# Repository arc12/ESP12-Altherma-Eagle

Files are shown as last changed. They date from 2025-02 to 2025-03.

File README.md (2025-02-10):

# ESP12 PCB for ESPAltherma

## Power
The normal use case, i.e. operating in the HP, is for the HP to power the board. JP1 is effectively an emergency disconnect feature and is normally on.

## Flashing
The firmware supports "Over The Air" updating but initial flashing will be via the Serial header. This initial flashing should be done without X10A being connected to the heat pump.

If testing with a 5V USB/Serial adapter attached to X10A then JP2 should be removed.

## Runtime Switches
__S1__ (Reset) - ESP-12 reset.
__S2__ is optional, see notes on Serial, below

## Headers
### Serial
UART pins and power, intended for initial flashing the device and diagnostic monitoring using a BT module. When using a Bluetooth serial monitor, JP2 should be on, to supply it with power. Note that the pin labels are to match those on the serial device, rather than being those of the ESP8622.  3.3V logic must be used.

Note that, if the DTR and RTS signals are connected (and D2 installed), then the PlatformIO monitor (or any other serial interaction which is not bootloading) must be configured as follows (add to platformio.ini), otherwise attempts to use the Monitor cause the board to hang (recovers if the monitor is killed):
```
monitor_rts = 0
monitor_dtr = 0
```

If DTR is not available on the USB/Serial adapter, install S2 and R16 and cut through SJ1 and SJ2 for manual boot-loader trigger.
__S2__ (Flash) -  Reset will trigger the boot loader if this switch is held on (i.e. flashing is done by holding S2 and then pressing/releasing S1). Once the new programme has been flashed, S1 (reset) must be done manually.

## Off-board "Thermo" Relay
See the ESPAltherma documentation for notes on the use of a relay to simulate a thermostat in order to on/off control the HP. This is a mains voltage relay AFAIK and in the interest of safety I decided to keep mains off the PCB. Hence there is a header to connect the GPIO to an off-board relay (which should ideally have an opto-coupler and suitable isolation gaps). A solder-jumper (SJ3) is used to allow selection of 3.3V or 5V for the header.

## Options
### LED Signalling
The battery of LEDs and associated Rs, plus JP3 allow for the output states to be signalled. JP3 allows for this signalling to be disconnected/reconnected as required. The external "thermo" relay is assumed to have its own signal.

If the LEDs are not fitted then the pad nearest to "L1", "SG1", etc may be used as a test point.

The ESP-12 modules have a LED on GPIO2, which is used as a "booted and running OK" signal.

### Bluetooth Monitoring
May be achieved by connecting a BT Serial module to the Serial header. Connect JP2 to power the module. NB this is 3.3V.

### Smart Grid OR Power Limitation
These two features use the same GPIO; only fit one set of components!

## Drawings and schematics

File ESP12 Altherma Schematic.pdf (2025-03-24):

## Device substitution:

TLP291-4 JST⁻EH JST⁻PA PCB TX/TX marking is correct for ESP⁸²⁶⁶ but RTS/DTR is correct for USB/Serial adapter.

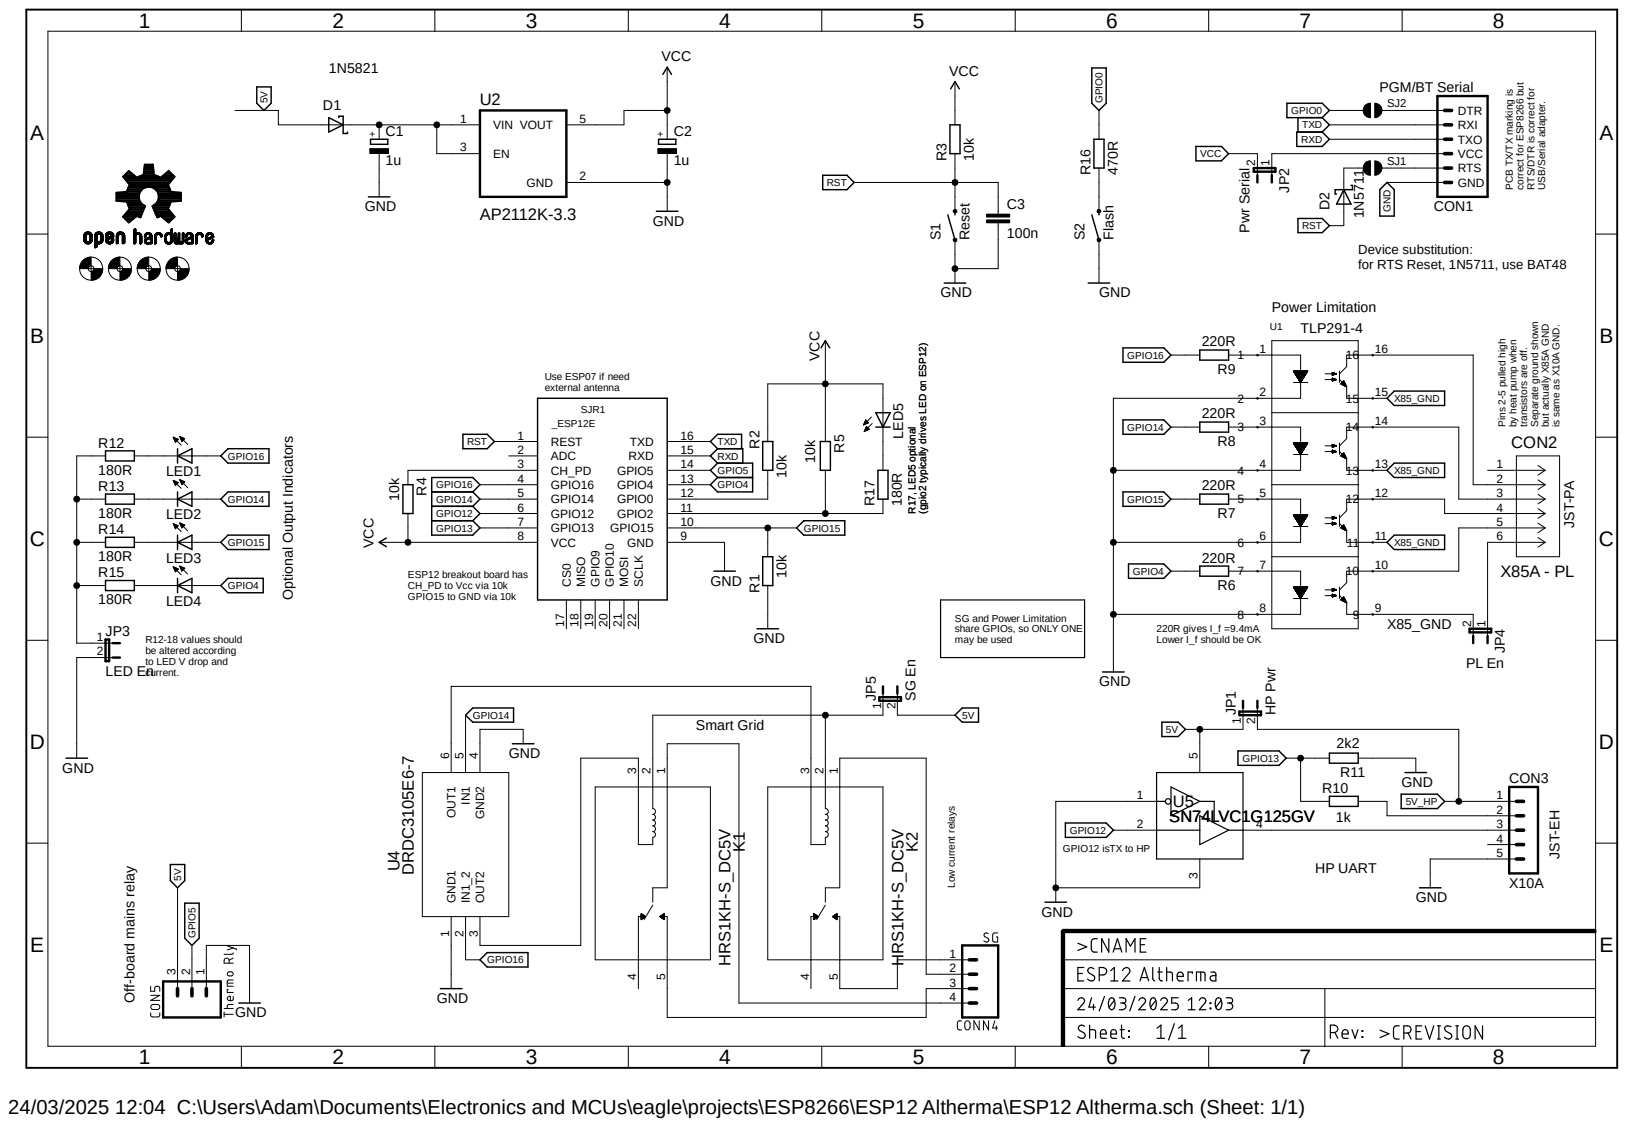
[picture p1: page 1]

for RTS Reset, 1N5711, use BAT48

external antenna Optional Output Indicators

SG and Power Limitation
share GPIOs, so ONLY ONE
may be used

R12-18 values should
be altered according
to LED V drop and
LED En

GPIO12 isTX to HP Low current relays

HP UART Off-board mains relay

24/03/2025 12:04 C:\Users\Adam\Documents\Electronics and MCUs\eagle\projects\ESP8266\ESP12 Altherma\ESP12 Altherma.sch (Sheet: 1/1)

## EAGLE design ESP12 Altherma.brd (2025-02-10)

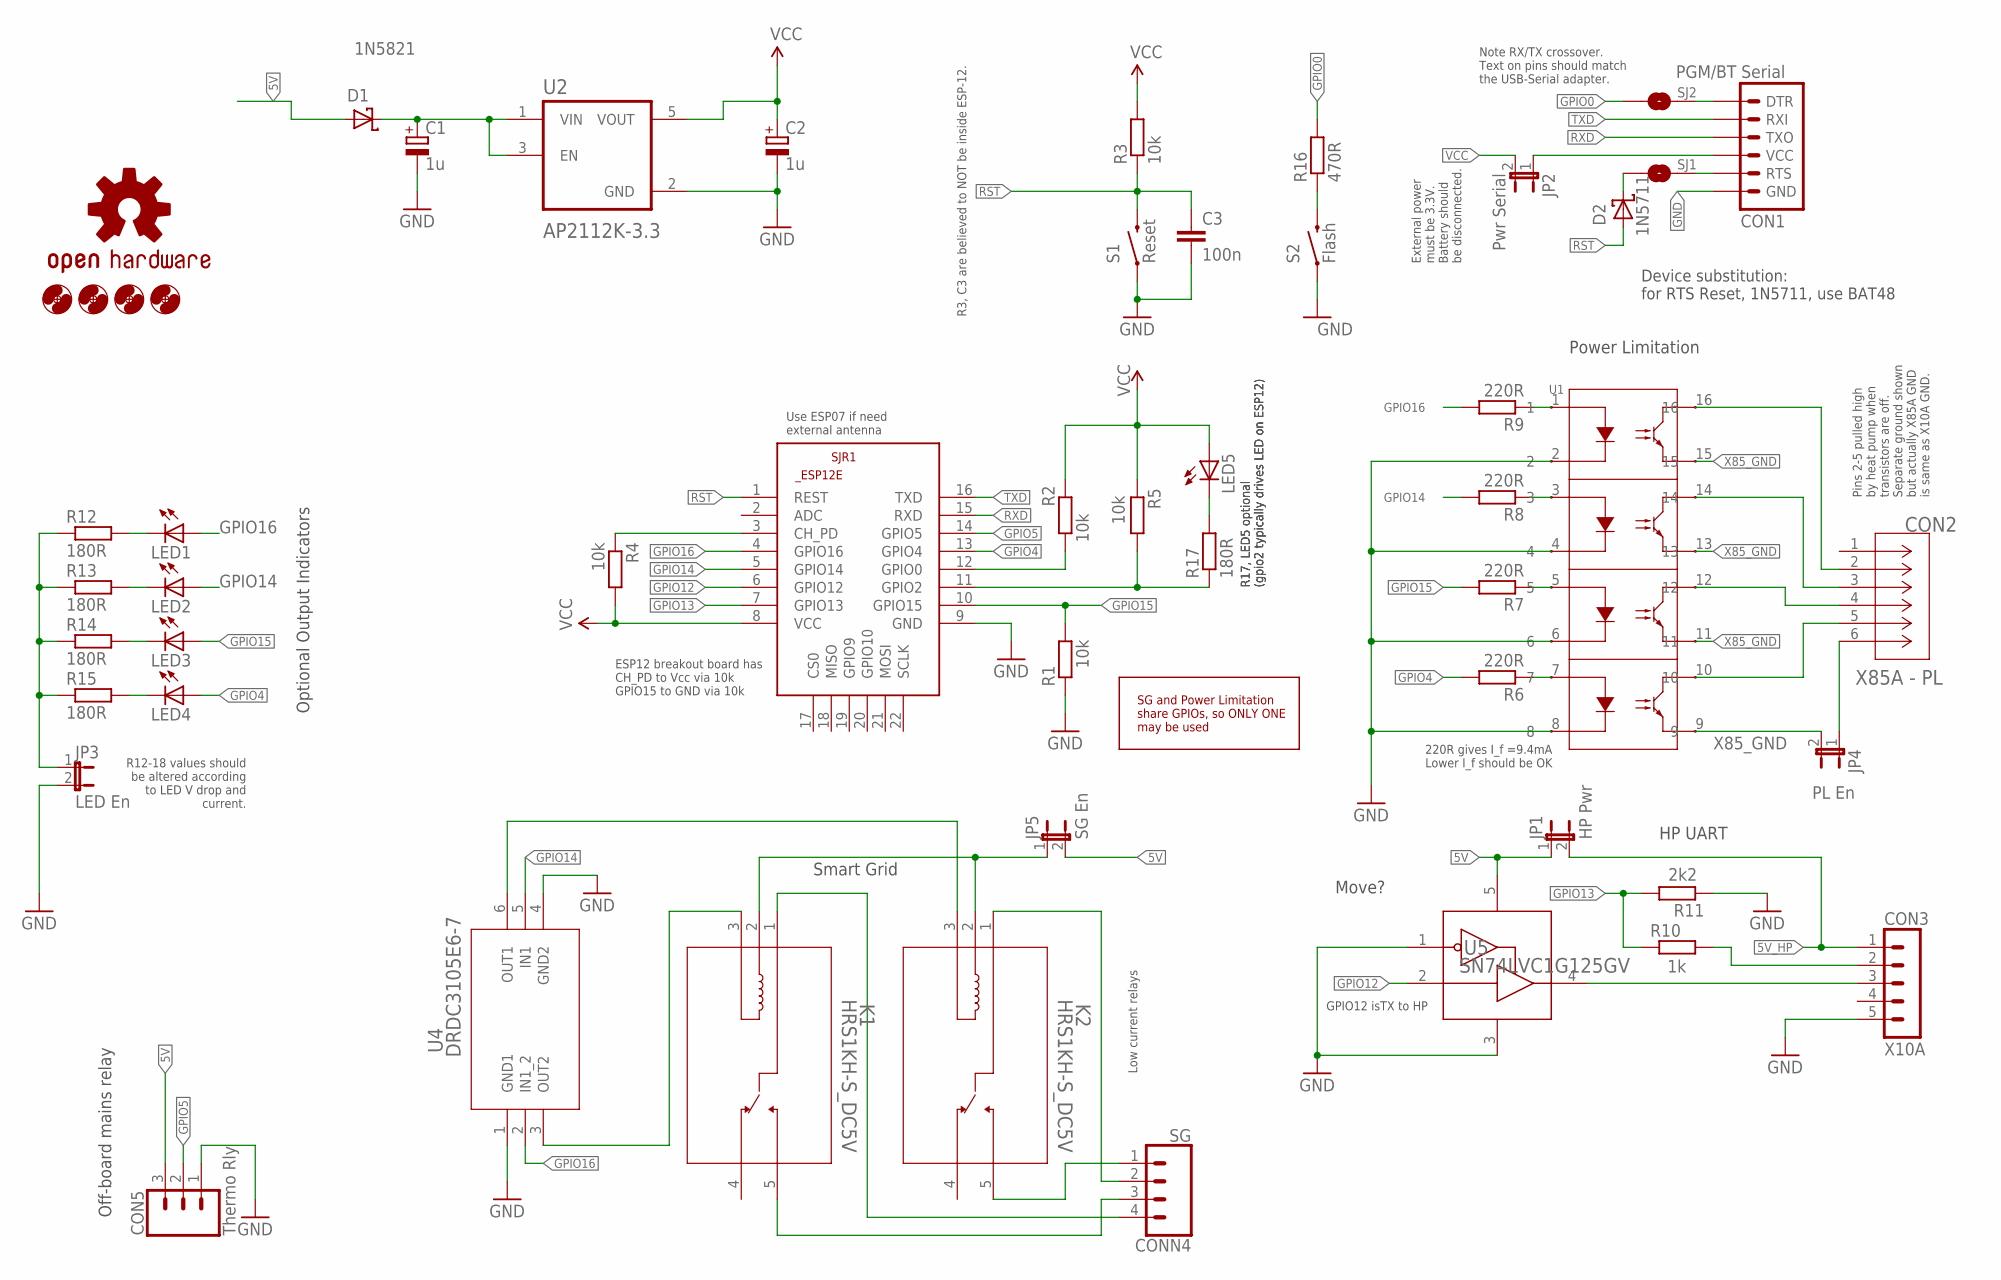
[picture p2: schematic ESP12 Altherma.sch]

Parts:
C1, C2: 1u; E2,5-5
C3: 100n; 1206
CON1: PGM/BT Serial; 1X06-KIT
CON2: X85A - PL; CONN_B06B-PASK_JST
CON3: X10A; B5B-EH-A
CON5: Thermo Rly; 1X03
CONN4: SG; 1X04
D1: 1N5821; DO201-15
D2: 1N5711; DO35-7
H1, H2, H3, H4: MOUNT-HOLE3.2; 3,2
JP1: HP Pwr; 1X02
JP2: Pwr Serial; 1X02
JP3: LED En; 1X02
JP4: PL En; 1X02
JP5: SG En; 1X02
K1, K2: HRS1KH-S_DC5V; HRS1KH-S_DC5V_MTC
LED1, LED2, LED3, LED4, LED5: LED1206; LED-1206
LOGO1: OSHW-LOGOM; OSHW-LOGO-M
R1, R2, R3, R4, R5: 10k; 1206
R6, R7, R8, R9: 220R; 1206
R10: 1k; 1206
R11: 2k2; 1206
R12, R13, R14, R15, R17: 180R; 1206
R16: 470R; 0204/7
S1: Reset; TACTILE-PTH
S2: Flash; TACTILE-PTH
SJ1, SJ2: SOLDERJUMPERTRACE; SJ_2S-TRACE
SJR1: ESP8266-12EESP8266-ESP12E-X; ESP8266-ESP12E0-NKE
U1: TLP291-4; SO16_TOS
U2: AP2112K-3.3; SOT95P285X140-5N
U4: DRDC3105E6-7; SOT26-DI_DIO-M
U5: SN74LVC1G125GV; DBV0005A_L

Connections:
5V: CON5.3, D1.A, JP1.1, JP5.2, U5.5 (VCC)
5V_HP: CON3.1, JP1.2
GND: C1.-, C2.-, C3.2, CON1.1 (GND), CON3.5, CON5.1, JP3.2, R1.1, R11.1, S1.1, S2.1, SJR1.9 (GND), U1.2, U1.4, U1.6, U1.8, U2.2 (GND), U4.1 (GND1), U4.4 (GND2), U5.1 (OE_N), U5.3 (GND)
GPIO0: R2.1, R16.2, SJ2.1, SJR1.12 (GPIO0)
GPIO2: R5.2, R17.1, SJR1.11 (GPIO2)
GPIO4: LED4.A, R6.2, SJR1.13 (GPIO4)
GPIO5: CON5.2, SJR1.14 (GPIO5)
GPIO12: SJR1.6 (GPIO12), U5.2 (A)
GPIO13: R10.1, R11.2, SJR1.7 (GPIO13)
GPIO14: LED2.A, R8.2, SJR1.5 (GPIO14), U4.5 (IN1)
GPIO15: LED3.A, R1.2, R7.2, SJR1.10 (GPIO15)
GPIO16: LED1.A, R9.2, SJR1.4 (GPIO16), U4.2 (IN1_2)
unnamed: R16.1, S2.3 (2)
unnamed: R9.1, U1.1
unnamed: CON2.3, U1.14
unnamed: JP3.1, R12.1, R13.1, R14.1, R15.1
unnamed: CON1.2 (RTS), SJ1.2
unnamed: JP5.1, K1.2, K2.2
unnamed: LED3.C, R14.2
unnamed: C1.+, D1.C, U2.1 (VIN), U2.3 (EN)
unnamed: CON1.3 (VCC), JP2.1
unnamed: CON1.6 (DTR), SJ2.2
unnamed: CON2.5, U1.10
unnamed: CON2.4, U1.12
unnamed: CON2.2, U1.16
unnamed: D2.C, SJ1.1
unnamed: LED4.C, R15.2
unnamed: R4.1, SJR1.3 (CH_PD)
unnamed: R6.1, U1.7
unnamed: R8.1, U1.3
unnamed: R7.1, U1.5
unnamed: CON3.3, U5.4 (Y)
unnamed: CON3.2, R10.2
unnamed: CONN4.1, K2.5
unnamed: CONN4.2, K2.1
unnamed: CONN4.3, K1.5
unnamed: CONN4.4, K1.1
unnamed: K1.3, U4.3 (OUT2)
unnamed: CON2.6, JP4.1
unnamed: LED5.C, R17.2
unnamed: K2.3, U4.6 (OUT1)
unnamed: LED1.C, R12.2
unnamed: LED2.C, R13.2
RST: C3.1, D2.A, R3.1, S1.3 (2), SJR1.1 (REST)
RXD: CON1.4 (TXO), SJR1.15 (RXD)
TXD: CON1.5 (RXI), SJR1.16 (TXD)
VCC: C2.+, JP2.2, LED5.A, R2.2, R3.2, R4.2, R5.1, SJR1.8 (VCC), U2.5 (VOUT)
X85_GND: JP4.2, U1.9, U1.11, U1.13, U1.15

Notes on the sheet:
R3, C3 are believed to NOT be inside ESP-12.
ESP12 breakout board has CH_PD to Vcc via 10k GPIO15 to GND via 10k
Note RX/TX crossover. Text on pins should match the USB-Serial adapter.
External power must be 3.3V. Battery should be disconnected.
R12-18 values should be altered according to LED V drop and current.
Device substitution: for RTS Reset, 1N5711, use BAT48
GPIO12 isTX to HP
Low current relays
Use ESP07 if need external antenna
Optional Output Indicators
Power Limitation
Smart Grid
HP UART
Off-board mains relay
220R gives I_f =9.4mA Lower I_f should be OK
Move?
Pins 2-5 pulled high by heat pump when transistors are off. Separate ground shown but actually X85A GND is same as X10A GND.
SG and Power Limitation share GPIOs, so ONLY ONE may be used
R17, LED5 optional (gpio2 typically drives LED on ESP12)

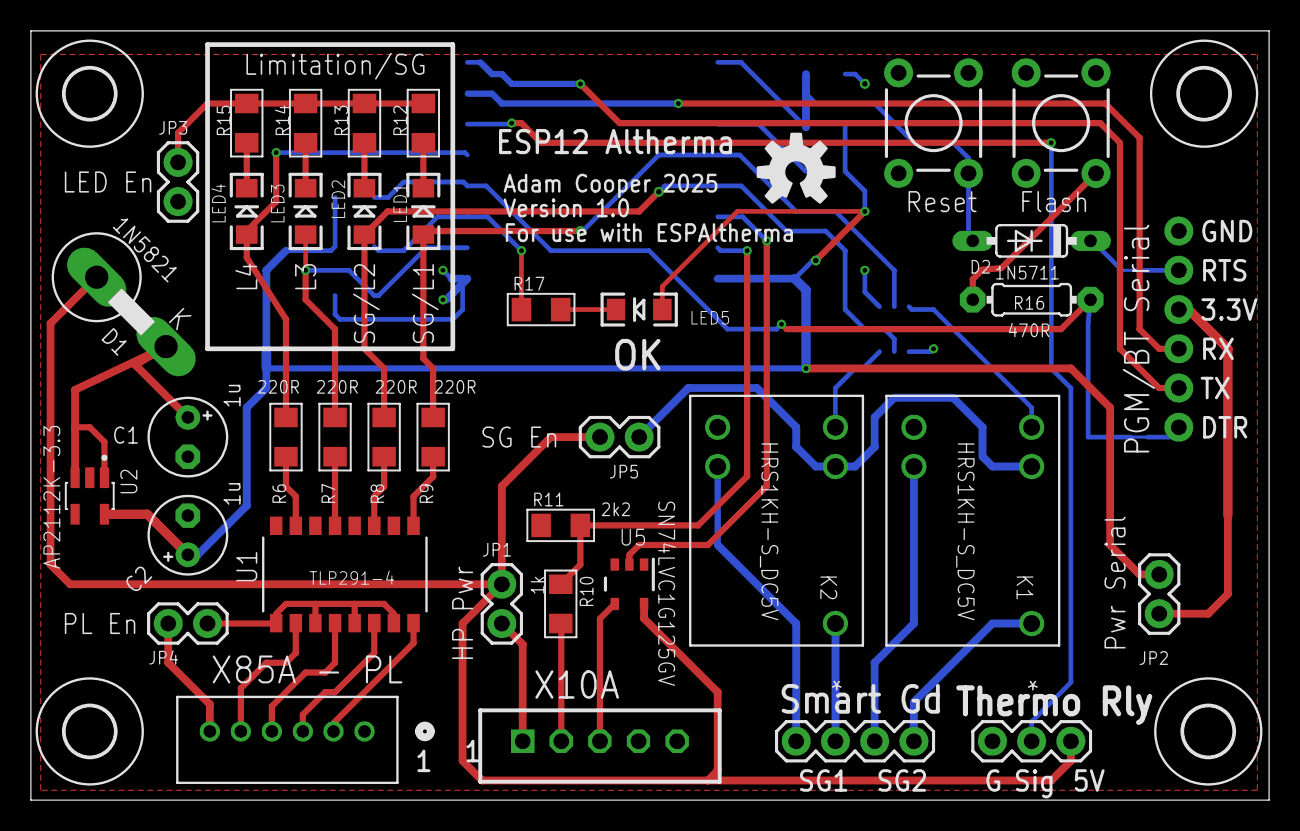
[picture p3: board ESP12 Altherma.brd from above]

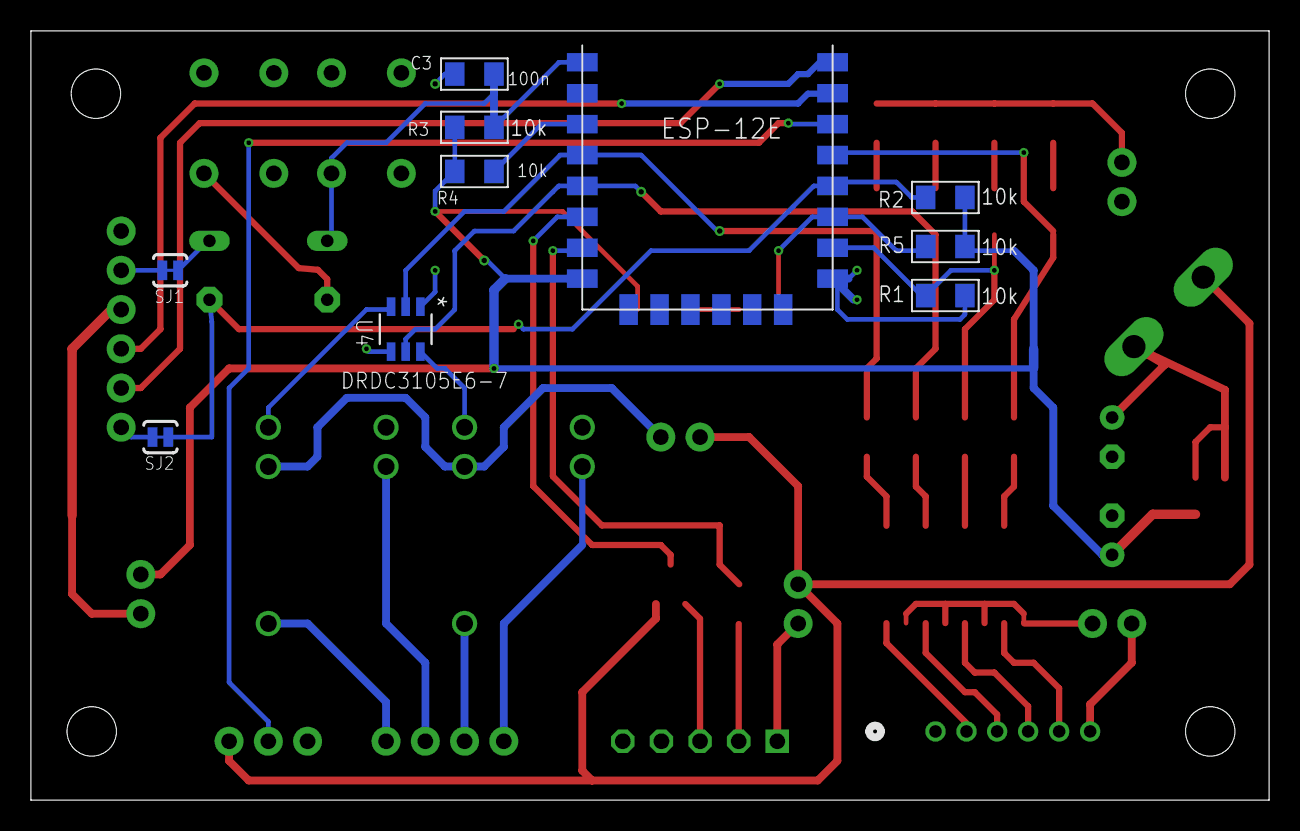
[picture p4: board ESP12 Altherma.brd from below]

Board: 2 copper layers, 80.1 x 49.8 mm, 53 parts (10 on the bottom side), 48 nets.

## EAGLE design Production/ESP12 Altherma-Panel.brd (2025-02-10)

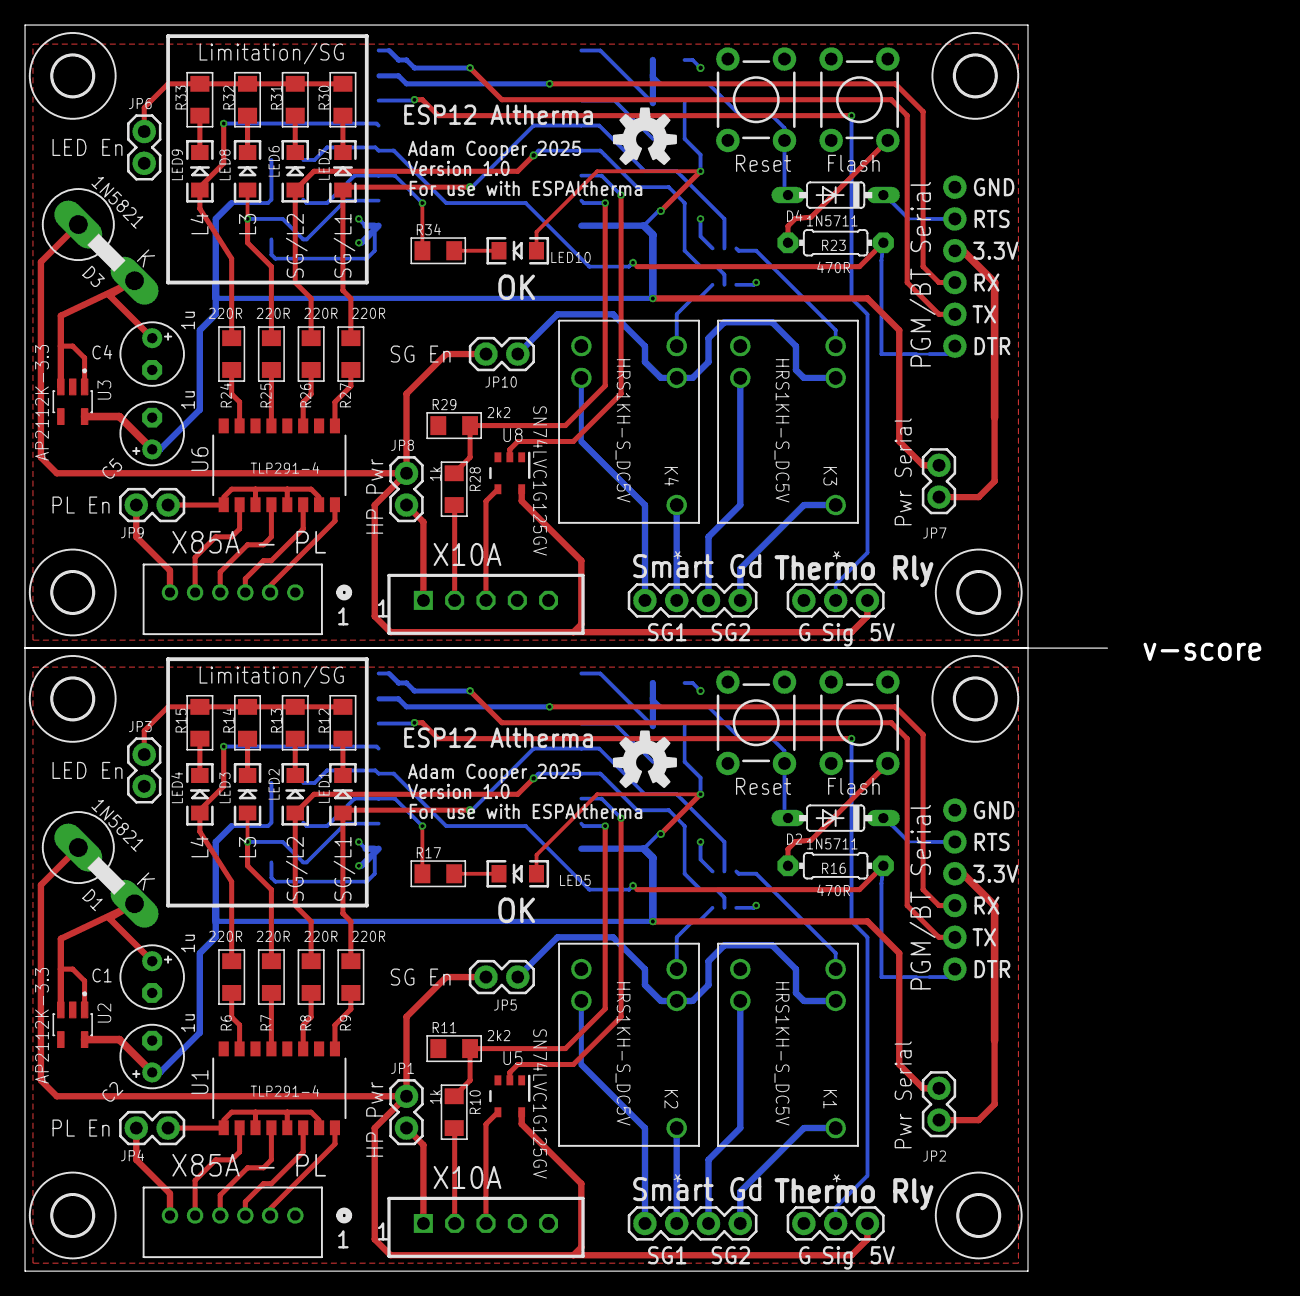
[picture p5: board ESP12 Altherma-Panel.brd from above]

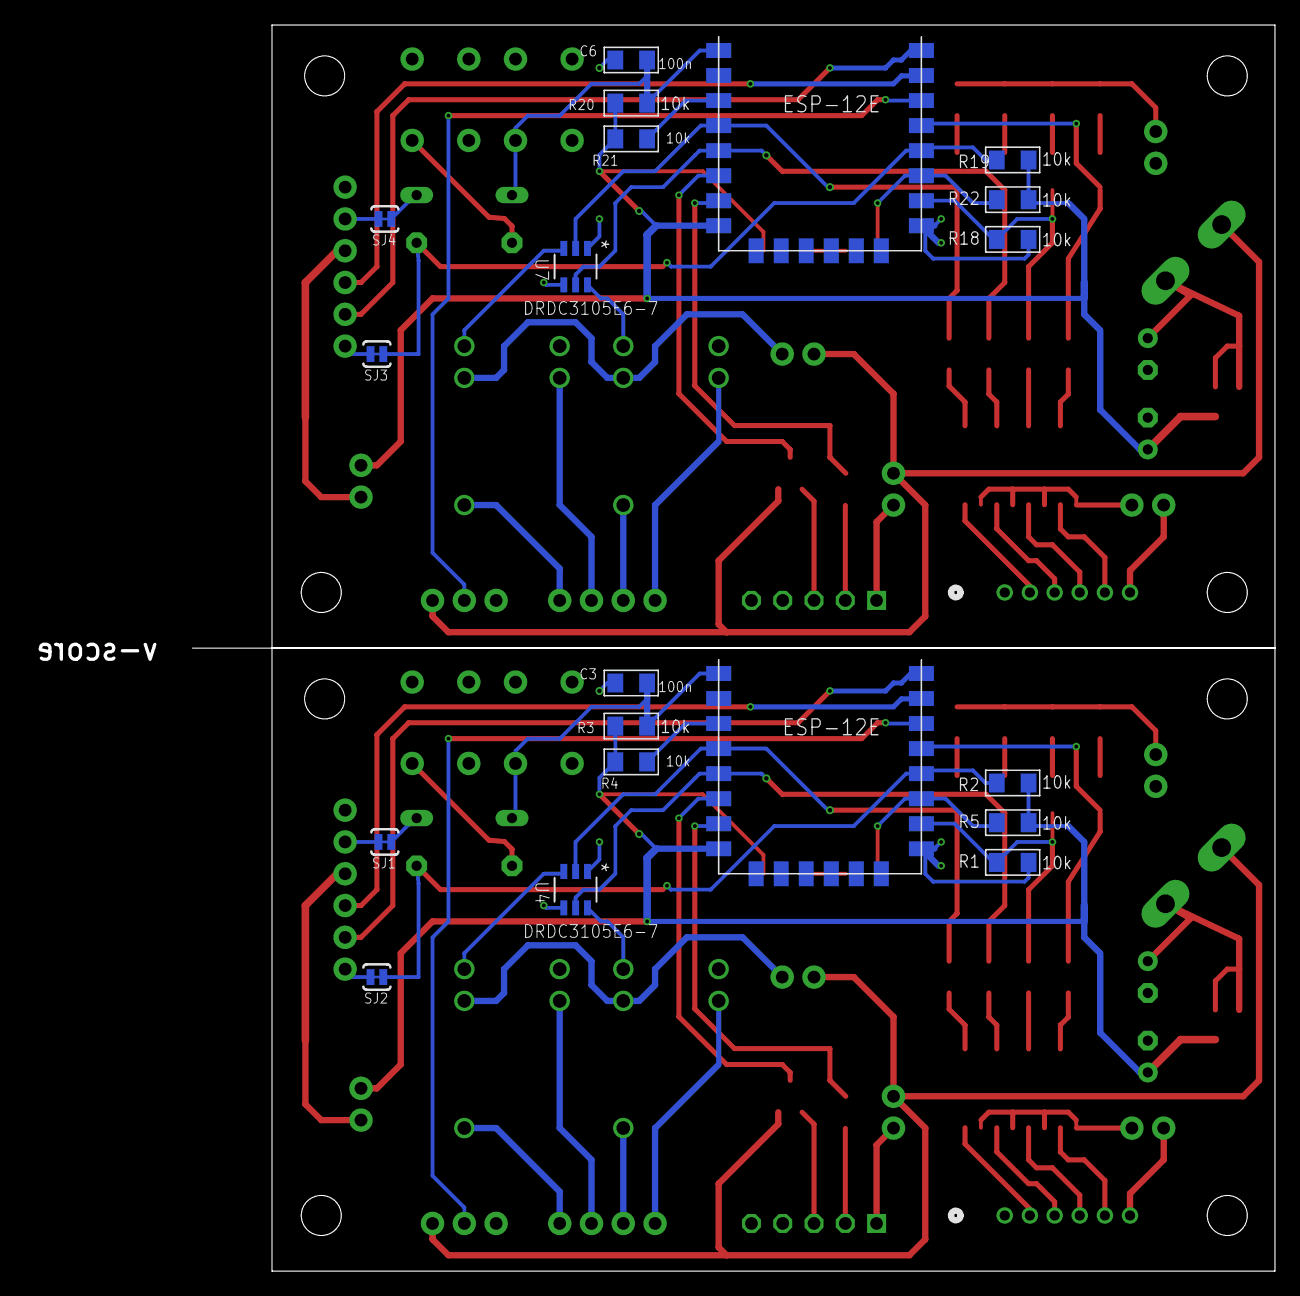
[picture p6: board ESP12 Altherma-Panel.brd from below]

Board: 2 copper layers, 86.5 x 99.6 mm, 106 parts (20 on the bottom side), 96 nets.

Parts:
C1, C2, C4, C5: 1u; E2,5-5
C3, C6: 100n; 1206
CON1, CON4: PGM/BT Serial; 1X06-KIT
CON2, CON8: X85A - PL; CONN_B06B-PASK_JST
CON3, CON7: X10A; B5B-EH-A
CON5, CON6: Thermo Rly; 1X03
CONN1, CONN4: SG; 1X04
D1, D3: 1N5821; DO201-15
D2, D4: 1N5711; DO35-7
H1, H2, H3, H4, H5, H6, H7, H8: MOUNT-HOLE3.2; 3,2
JP1, JP8: HP Pwr; 1X02
JP2, JP7: Pwr Serial; 1X02
JP3, JP6: LED En; 1X02
JP4, JP9: PL En; 1X02
JP5, JP10: SG En; 1X02
K1, K2, K3, K4: HRS1KH-S_DC5V; HRS1KH-S_DC5V_MTC
LED1, LED2, LED3, LED4, LED5, LED6, LED7, LED8, LED9, LED10: LED-1206
LOGO1, LOGO2: OSHW-LOGOM; OSHW-LOGO-M
R1, R2, R3, R4, R5, R18, R19, R20, R21, R22: 10k; 1206
R6, R7, R8, R9, R24, R25, R26, R27: 220R; 1206
R10, R28: 1k; 1206
R11, R29: 2k2; 1206
R12, R13, R14, R15, R17, R30, R31, R32, R33, R34: 180R; 1206
R16, R23: 470R; 0204/7
S1, S3: Reset; TACTILE-PTH
S2, S4: Flash; TACTILE-PTH
SJ1, SJ2, SJ3, SJ4: SOLDERJUMPERTRACE; SJ_2S-TRACE
SJR1, SJR2: ESP8266-ESP12E0-NKE
U1, U6: TLP291-4; SO16_TOS
U2, U3: AP2112K-3.3; SOT95P285X140-5N
U4, U7: DRDC3105E6-7; SOT26-DI_DIO-M
U5, U8: SN74LVC1G125GV; DBV0005A_L

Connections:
5V: CON5.3, D1.A, JP1.1, JP5.2, U5.5
5V1: CON6.3, D3.A, JP8.1, JP10.2, U8.5
5V_HP: CON3.1, JP1.2
5V_HP1: CON7.1, JP8.2
GND: C1.-, C2.-, C3.2, CON1.1, CON3.5, CON5.1, JP3.2, R1.1, R11.1, S1.1, S2.1, SJR1.9, U1.2, U1.4, U1.6, U1.8, U2.2, U4.1, U4.4, U5.1, U5.3
GND1: C4.-, C5.-, C6.2, CON4.1, CON6.1, CON7.5, JP6.2, R18.1, R29.1, S3.1, S4.1, SJR2.9, U3.2, U6.2, U6.4, U6.6, U6.8, U7.1, U7.4, U8.1, U8.3
GPIO0: R2.1, R16.2, SJ2.1, SJR1.12
GPIO1: LED9.A, R24.2, SJR2.13
GPIO2: R5.2, R17.1, SJR1.11
GPIO3: CON6.2, SJR2.14
GPIO4: LED4.A, R6.2, SJR1.13
GPIO5: CON5.2, SJR1.14
GPIO6: SJR2.6, U8.2
GPIO7: R28.1, R29.2, SJR2.7
GPIO8: LED6.A, R26.2, SJR2.5, U7.5
GPIO9: R19.1, R23.2, SJ3.1, SJR2.12
GPIO10: R22.2, R34.1, SJR2.11
GPIO11: LED7.A, R27.2, SJR2.4, U7.2
GPIO12: SJR1.6, U5.2
GPIO13: R10.1, R11.2, SJR1.7
GPIO14: LED2.A, R8.2, SJR1.5, U4.5
GPIO15: LED3.A, R1.2, R7.2, SJR1.10
GPIO16: LED1.A, R9.2, SJR1.4, U4.2
GPIO17: LED8.A, R18.2, R25.2, SJR2.10
unnamed: R16.1, S2.3
unnamed: R9.1, U1.1
unnamed: CON2.3, U1.14
unnamed: JP3.1, R12.1, R13.1, R14.1, R15.1
unnamed: CON1.2, SJ1.2
unnamed: JP5.1, K1.2, K2.2
unnamed: LED3.C, R14.2
unnamed: C1.+, D1.C, U2.1, U2.3
unnamed: CON1.3, JP2.1
unnamed: CON1.6, SJ2.2
unnamed: CON2.5, U1.10
unnamed: CON2.4, U1.12
unnamed: CON2.2, U1.16
unnamed: D2.C, SJ1.1
unnamed: LED4.C, R15.2
unnamed: R4.1, SJR1.3
unnamed: R6.1, U1.7
unnamed: R8.1, U1.3
unnamed: R7.1, U1.5
unnamed: CON3.3, U5.4
unnamed: CON3.2, R10.2
unnamed: CONN4.1, K2.5
unnamed: CONN4.2, K2.1
unnamed: CONN4.3, K1.5
unnamed: CONN4.4, K1.1
unnamed: K1.3, U4.3
unnamed: CON2.6, JP4.1
unnamed: LED5.C, R17.2
unnamed: K2.3, U4.6
unnamed: R21.1, SJR2.3
unnamed: R23.1, S4.3
unnamed: C4.+, D3.C, U3.1, U3.3
unnamed: CON4.3, JP7.1
unnamed: CON4.6, SJ3.2
unnamed: CON4.2, SJ4.2
unnamed: D4.C, SJ4.1
unnamed: CON8.5, U6.10
unnamed: CON8.4, U6.12
unnamed: LED1.C, R12.2
unnamed: LED2.C, R13.2
unnamed: CON8.3, U6.14
unnamed: CON8.2, U6.16
unnamed: R24.1, U6.7
unnamed: R27.1, U6.1
unnamed: R26.1, U6.3
unnamed: R25.1, U6.5
unnamed: CON7.3, U8.4
unnamed: CON7.2, R28.2
unnamed: CONN1.1, K4.5
unnamed: CONN1.3, K3.5
unnamed: CONN1.2, K4.1
unnamed: CONN1.4, K3.1
unnamed: K3.3, U7.3
unnamed: K4.3, U7.6
unnamed: JP6.1, R30.1, R31.1, R32.1, R33.1
unnamed: LED8.C, R32.2
unnamed: LED9.C, R33.2
unnamed: LED7.C, R30.2
unnamed: LED6.C, R31.2
unnamed: CON8.6, JP9.1
unnamed: JP10.1, K3.2, K4.2
unnamed: LED10.C, R34.2
RST: C3.1, D2.A, R3.1, S1.3, SJR1.1
RST1: C6.1, D4.A, R20.1, S3.3, SJR2.1
RXD: CON1.4, SJR1.15
RXD1: CON4.4, SJR2.15
TXD: CON1.5, SJR1.16
TXD1: CON4.5, SJR2.16
VCC: C2.+, JP2.2, LED5.A, R2.2, R3.2, R4.2, R5.1, SJR1.8, U2.5
VCC1: C5.+, JP7.2, LED10.A, R19.2, R20.2, R21.2, R22.1, SJR2.8, U3.5
X85_GND: JP4.2, U1.9, U1.11, U1.13, U1.15
X85_GND1: JP9.2, U6.9, U6.11, U6.13, U6.15

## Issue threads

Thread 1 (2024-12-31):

Add reset reed relay

arc12, 2024-12-31:
i.e. allow for hardware reset without opening the case

may be useful if the electronics is sited outside the HP cabinet, which I think makes sense at least in the dev/prototyping stage, which is exactly when a reset is likely to be needed

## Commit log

2024-03-30 Complete prototype version, not properly checked and circuit not tested, let alone a PCB made!
    [ESP12 Altherma.brd, ESP12 Altherma.sch]
2025-02-09 shorten board. share GPIO for LP and SG. use JST connectors. tidy needless complexity
    [ESP12 Altherma.brd, ESP12 Altherma.sch]
2025-02-09 change esp12 to version without Restrict layer so I can panelise
    [ESP12 Altherma.brd, ESP12 Altherma.sch]
2025-02-09 Provisionally final tweaks prior to attempting panelisation
    [ESP12 Altherma.brd, ESP12 Altherma.sch]
2025-02-10 I think this is v1.0. This commit free of any panelisation guff.
    [ESP12 Altherma.brd, ESP12 Altherma.sch]
2025-02-10 silk tweak!
    [ESP12 Altherma.brd]
2025-02-10 Added layers 125/6 in BRD. Added panelised BRD.
    [ESP12 Altherma-Panel.brd]
2025-02-10 gerbers sent to Seeed for PCB fab
2025-03-24 clean up schematic
    [ESP12 Altherma.sch]

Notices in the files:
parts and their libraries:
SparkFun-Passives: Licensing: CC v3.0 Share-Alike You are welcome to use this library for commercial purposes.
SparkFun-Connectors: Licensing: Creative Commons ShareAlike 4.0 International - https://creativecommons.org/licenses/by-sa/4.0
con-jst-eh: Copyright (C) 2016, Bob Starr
